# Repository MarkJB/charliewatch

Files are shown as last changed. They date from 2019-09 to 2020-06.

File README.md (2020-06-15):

Charliewatch
---

An "Analog" watch with 72 (60+12) Charlieplexed LEDs. Based on Travis Goodspeed's
GoodWatch21 schematic, using the CC430F5137IRGZR CPU, which doesn't have the LCD
controller of the CC430F6xxx in the GoodWatch.

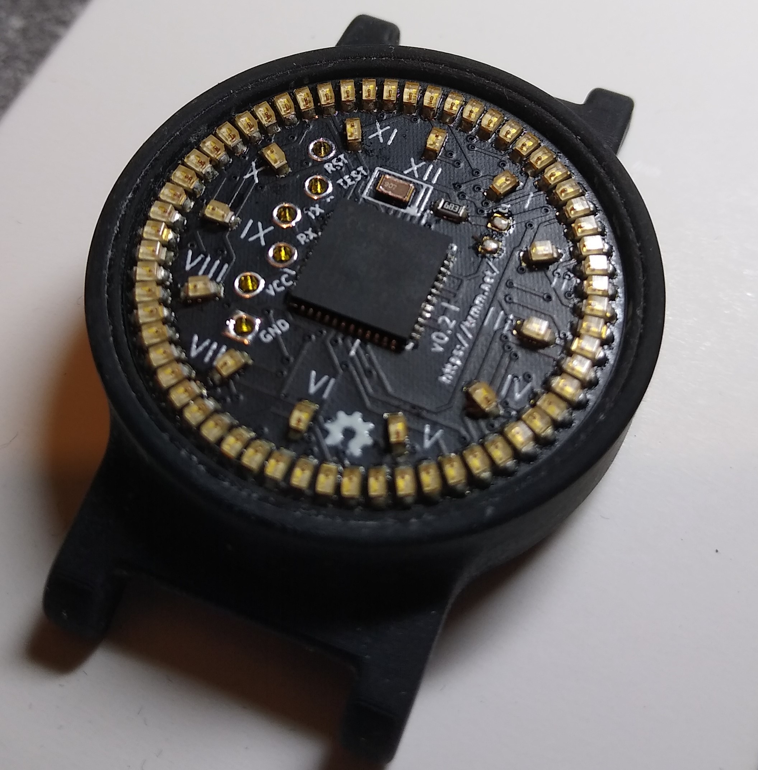
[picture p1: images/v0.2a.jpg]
Modified v0.2 board with Roman Numerals

v0.2 works, although it has no radio parts.  It is exactly 1 square inch
of PCB and should fit in a 38mm or 36mm case.

See it in action: https://www.youtube.com/watch?v=VaebR-6KNXE

[Charliewtch schematic](datasheets/charliewatch.pdf)

Bill Of Materials (BOM)
---
- CC430F5137IRGZR [https://www.mouser.co.uk/ProductDetail/595-CC430F5137IRGZR](https://www.mouser.co.uk/ProductDetail/595-CC430F5137IRGZR)

- 0603 68k Resistor [ERA3AEB683V](https://uk.farnell.com/panasonic/era3aeb683v/res-68k-0-1-0-1w-0603-thin-film/dp/1577630)

- 0603 Red LED [KP-1608EC](https://uk.farnell.com/kingbright/kp-1608ec/led-red-8mcd-625nm-smd/dp/2463988)

- KEYSTONE  3002  Battery Contact, Coin Cell - 20mm, SMD [3002](https://uk.farnell.com/keystone/3002/battery-smd-retainer-20mm/dp/1650693)

- IQD FREQUENCY PRODUCTS  LFXTAL050789  Crystal, 32.768 kHz, SMD, 2mm x 1.2mm, 12.5 pF, 20 ppm, IQXC-25 Series [LFXTAL050789](https://uk.farnell.com/iqd-frequency-products/lfxtal050789/crystal-32-768khz-12-5pf-smd/dp/2449502)

- Push button - Omron [B3U3100P](https://uk.farnell.com/omron/b3u-3000p/tactile-switch-side-actuated-smd/dp/1333655)

Programming
---

Programmed via TI Code Composer Studio using the Programmer/Debugger on the MSP430 FR4133 Launchpad.
http://www.ti.com/tool/MSP-EXP430FR4133

Programming cable
---

From the top of the board: (Wiring from watch to Programmer/Debugger on MSP430 FR4133 Launchpad) 
* TST - SBWTCK
* RST - SBWTDIO
* RX - RXD
* TX - TXD
* VCC - 3V3
* GND - GND

There is also a four-wire setup that might simplify the wiring.
Travis documents it and the power consumption here:
https://github.com/travisgoodspeed/goodwatch/wiki/EnergyTrace

Bricked Launchpad
-----

If you brick your launchpad by running Energia under Linux, it will no
longer program the Charliewatch.  The other weirdness is that `tilib`
can detect the device, but can't write to it unless run as root.

Energy Trace
----
* `libmsp430.so`: https://dlbeer.co.nz/articles/slac460y/index.html
* https://github.com/carrotIndustries/energytrace-util
* Have to update path to `MSP430.h` from the `slac/DLL430_v3/include` directory

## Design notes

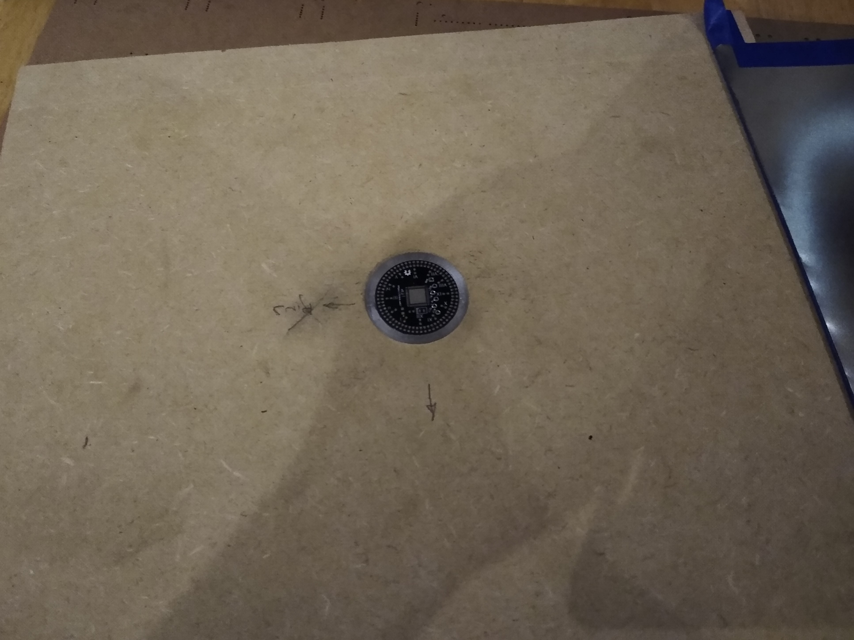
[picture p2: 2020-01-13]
images/pcb_puck3.jpg

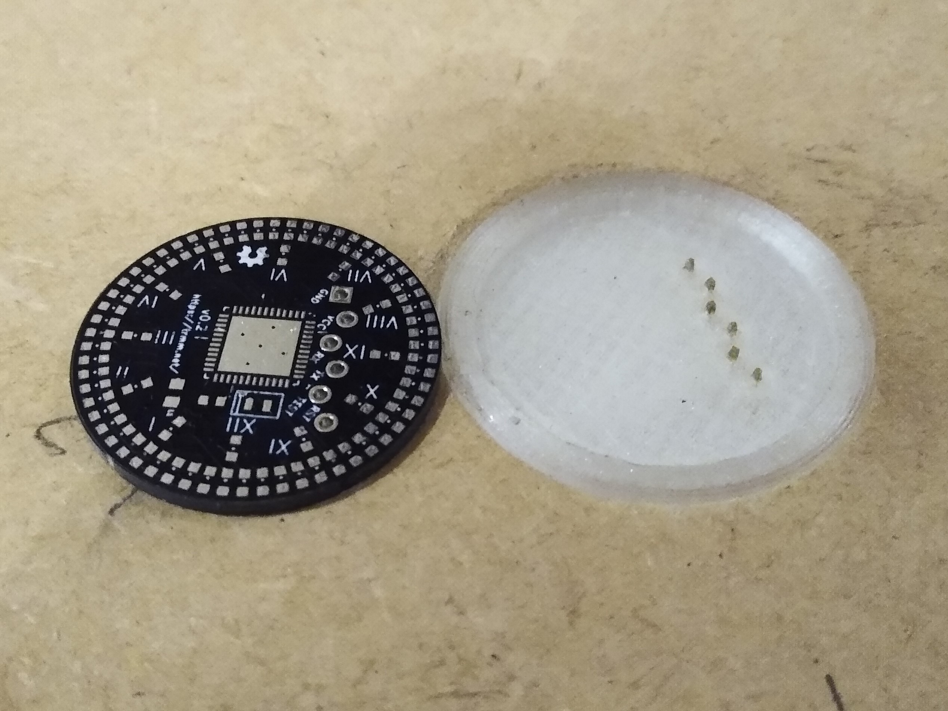
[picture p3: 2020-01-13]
images/pcb_puck2.jpg

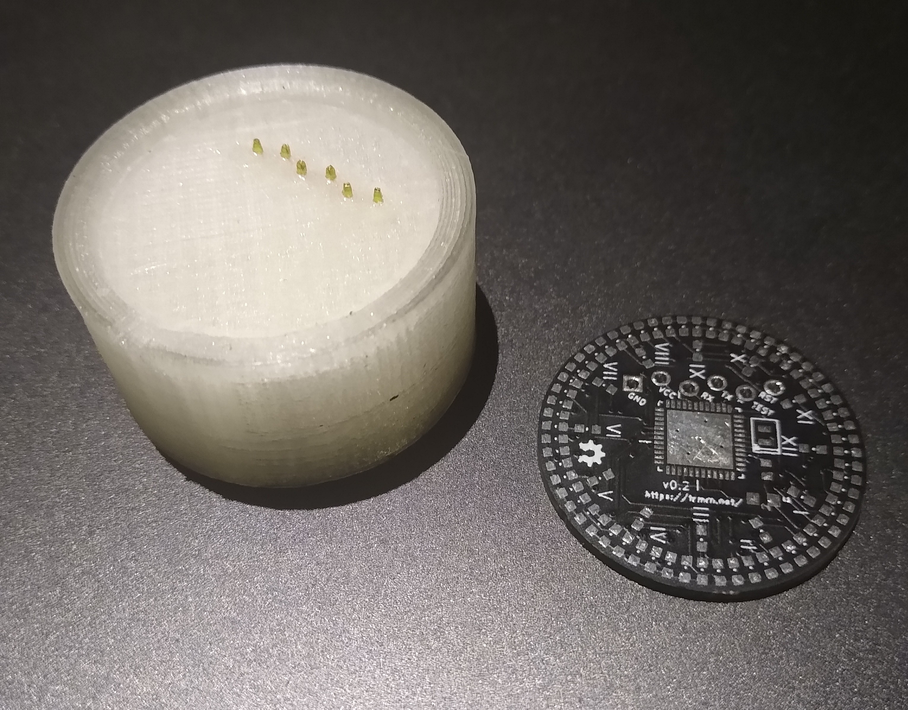
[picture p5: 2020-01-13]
images/pcb_puck1.jpg

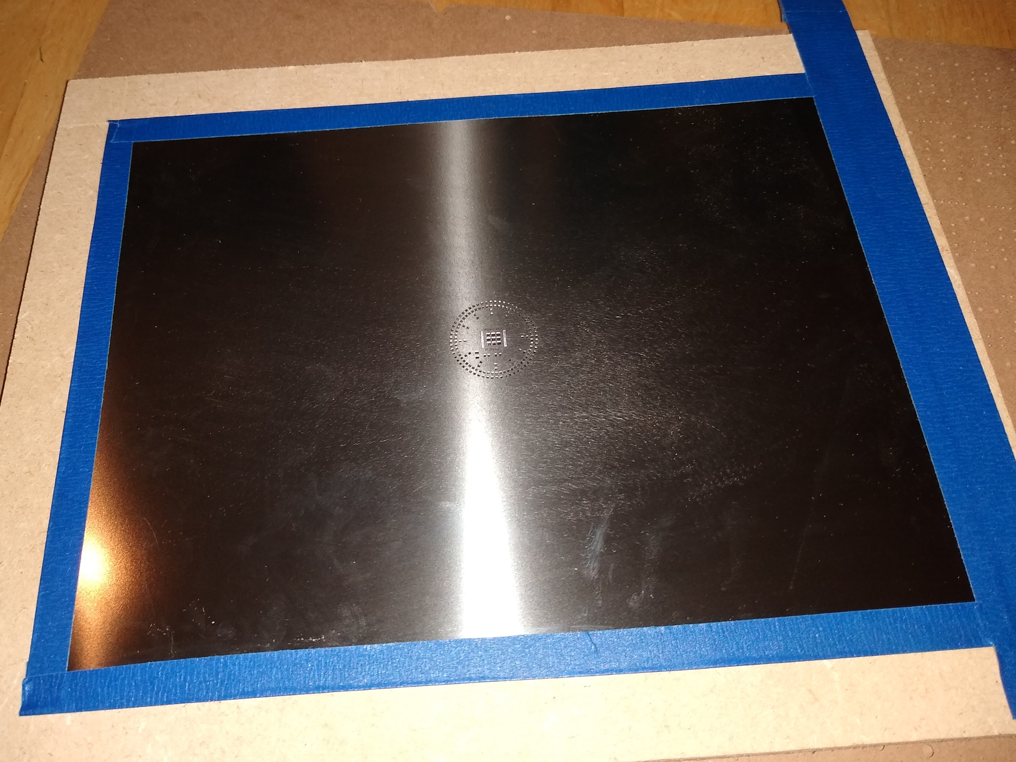
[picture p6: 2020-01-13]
images/pcb_puck4.jpg

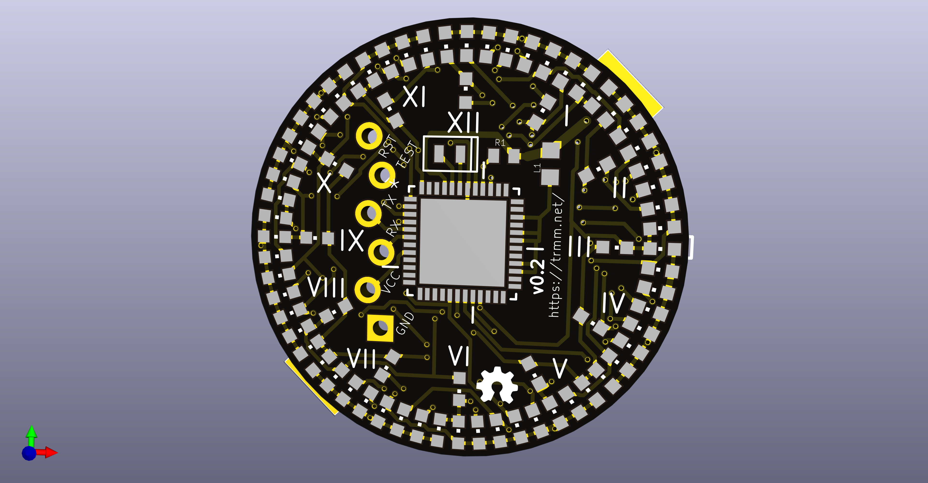
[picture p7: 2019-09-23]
pcb/charliewatch_black_roman_numerals.png

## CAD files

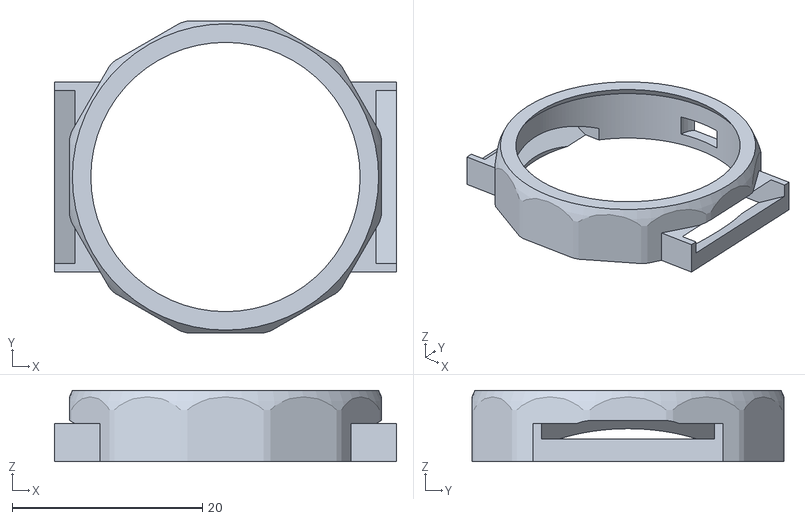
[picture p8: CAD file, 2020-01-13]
case/case.stl
36.0 x 32.8 x 7.50

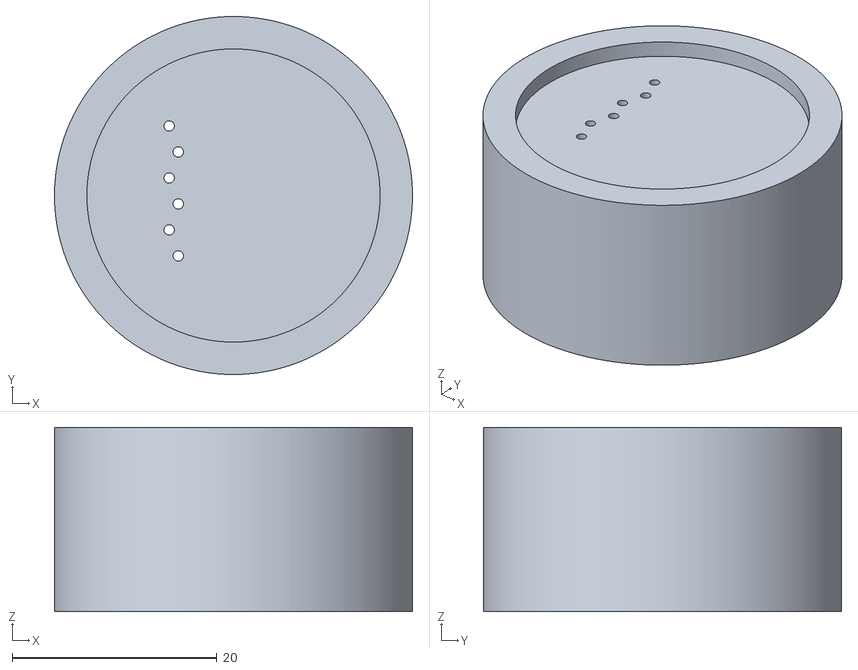
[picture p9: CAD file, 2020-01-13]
pcb/stencil_puck_35mm_drill.stl
35.0 x 35.0 x 18.0

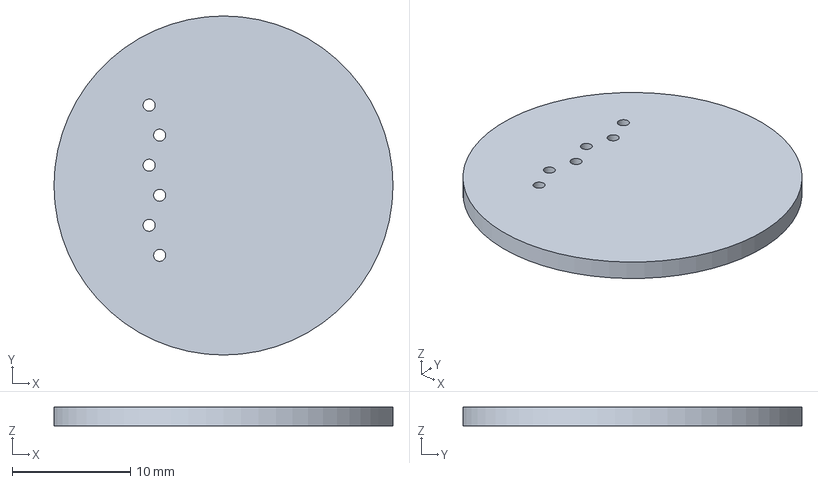
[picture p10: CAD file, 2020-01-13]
pcb/charliewatch-norf-routed.step
28.7 x 28.7 x 1.60 mm

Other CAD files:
case/case.scad
case/case.amf

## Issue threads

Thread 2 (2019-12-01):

No proven BOM

MarkJB, 2019-12-01:
Create a proven BOM (Note: Not yet tested)

Parts used so far:

- CC430F5137IRGZR [https://www.mouser.co.uk/ProductDetail/595-CC430F5137IRGZR](https://www.mouser.co.uk/ProductDetail/595-CC430F5137IRGZR)

- 0603 68k Resistor [ERA3AEB683V](https://uk.farnell.com/panasonic/era3aeb683v/res-68k-0-1-0-1w-0603-thin-film/dp/1577630)

- 0603 Red LED [KP-1608EC](https://uk.farnell.com/kingbright/kp-1608ec/led-red-8mcd-625nm-smd/dp/2463988)

- KEYSTONE  3002  Battery Contact, Coin Cell - 20mm, SMD [3002](https://uk.farnell.com/keystone/3002/battery-smd-retainer-20mm/dp/1650693)

- IQD FREQUENCY PRODUCTS  LFXTAL050789  Crystal, 32.768 kHz, SMD, 2mm x 1.2mm, 12.5 pF, 20 ppm, IQXC-25 Series [LFXTAL050789](https://uk.farnell.com/iqd-frequency-products/lfxtal050789/crystal-32-768khz-12-5pf-smd/dp/2449502)

- Push button - Omron [B3U3100P](https://uk.farnell.com/omron/b3u-3000p/tactile-switch-side-actuated-smd/dp/1333655)

MarkJB, 2020-01-02:
I can confirm that this BOM is correct so far - need to find a suitable button.

MarkJB, 2020-01-08:
Push button is Omron [B3U3100P](https://uk.farnell.com/omron/b3u-3000p/tactile-switch-side-actuated-smd/dp/1333655)

Closed 2020-01-08.

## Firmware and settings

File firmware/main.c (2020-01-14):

/*! \file main.c

  \brief Main module.  This version initializes the hardware and then
   drops to a low power mode, letting the WDT update the LEDs every 16ms

  Schematic and more at https://trmm.net/Charliewatch
*/

#include <msp430.h>
#include <string.h>
#include <stdio.h>
#include <stdlib.h>

#include "rtc.h"
#include "ucs.h"
#include "led.h"
#include "adc.h"
#include "power.h"
#include "button.h"

//! Activates and configures the module, but does not turn on reference.
void ref_init(){
  //Setting the master bit disables legacy mode.
  REFCTL0|=REFMSTR;

  //Wait for register to not be busy before modifying voltage.
  while(REFCTL0 & REFGENBUSY);
  
  //2.5V reference.
  REFCTL0 &= ~BGMODE;
  REFCTL0|=REFVSEL_2;
}


//! Main method.
int main(void)
{
	WDTCTL = WDTPW + WDTHOLD; // Stop WDT

	ref_init();
	//uart_init();

	// drive port J and 1 to ground to avoid CMOS power drain
	PJDIR |=  0xF;
	PJOUT &= ~0xF;
	P1DIR |=  0xF;
	P1OUT &= ~0xF;

	button_init();

	// turn off all the LEDs to reduce power
	led_off();

#if 1
	led_test();
#else
	while(1) {
		led_test();
		delay(1000);
	}
#endif

	rtc_init();
	ucs_init(); // doesn't work if crystal isn't there?

	// Setup and enable WDT 16ms, ACLK, interval timer
	WDTCTL = WDT_ADLY_16;
	SFRIE1 |= WDTIE;

	// go into low power mode
	power_setvcore(0);
	ucs_slow();

	__bis_SR_register(LPM3_bits + GIE);        // Enter LPM3

	// flash the 0 hour so that we know something is wrong
	while(1)
	{
		led_on(60); delay(1);
		led_off(); delay(3);
		led_on(60); delay(1);
		led_off(); delay(6);
	}
}


extern void stopwatch_draw(void);
extern void clockset_draw(void);
extern void animation_draw(void);
extern void lowpwr_draw(void);

static void voltage_draw(void)
{
	unsigned i;
	unsigned raw_volts = adc12_single_conversion(
		REFVSEL_1, ADC12SHT0_10, ADC12INCH_11);


#if 0
	static unsigned bright = 0;
	bright = (bright + 1) % 128;

	for(i = 0 ; i < 12 ; i++)
	{
		if (0 == (raw_volts & (1<<i)))
			continue;
		led_dither(60+i, bright > 64 ? 128 - bright : bright);
	}

	unsigned scaled = raw_volts / 68;
	for(i = 0 ; i < scaled ; i++)
	{
		led_on(i);
	}
#else
	unsigned millivolts = (1250 * (uint32_t) raw_volts) / 1024;
	led_on(60 + (millivolts / 1000));

	unsigned mv = ((millivolts % 1000) * 60) / 1000;
	for(i = 0 ; i < mv ; i++)
	{
		led_on(i);
	}
#endif
		
	led_off();
}

static void (*const modes[])(void) = {
	//voltage_draw,
	animation_draw, //mode 0 display time
	stopwatch_draw, //mode 1 stopwatch
	clockset_draw, //mode 2 (2a) set hours
	clockset_draw, //mode 3 (2b) minutes
	voltage_draw,  //mode 4 hr=3 battery level
	lowpwr_draw,   //mode 5 hr=4 leds off (short press to enable or will timeout)
};

static const unsigned mode_count = sizeof(modes) / sizeof(*modes);
unsigned watch_mode = 0;


//! Watchdog Timer interrupt service routine, calls back to handler functions.
void __attribute__ ((interrupt(WDT_VECTOR)))
watchdog_timer(void)
{
	ucs_fast();

	button_update();

	// long hold advances mode
	if (button_long)
		watch_mode = (watch_mode + 1) % mode_count;

	modes[watch_mode]();

	led_off();
	ucs_slow();
}

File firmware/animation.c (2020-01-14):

/*! \file animation.c

  \brief Drawing functions based on the time.

Animations are drawn:
* When the second hand hits the minute hand
* When the second hand hits the minute hand on a 5 minut emark
* When the second hand hits the hour hand
* When all three hands line up
* At midnight/noon
*/

#include <msp430.h>
#include <string.h>
#include <stdio.h>
#include <stdlib.h>

#include "led.h"
#include "button.h"

extern unsigned watch_mode;

void delay(unsigned len)
{
#if 0
	const uint8_t p2 = P2OUT;
	const uint8_t p3 = P3OUT;

	while(len)
	{
		// toggle the LEDs back on
		P2OUT = p2;
		P3OUT = p3;
		len--;

		// now toggle them off
		P2OUT = 0;
		P3OUT = 0;
	}
#else
	len *= 2;
	while(len)
	{
		asm("");
		len--;
	}
#endif
}


// In normal operation there are four LEDs powered on
// The minute is full bright
// The hour is half bright
// the second is quarter bright
// the previous second fades
uint8_t led_display[] = {};
uint8_t led_bright[] = {};


void led_draw(void)
{
	int i;

	for(i=0 ; i < NUM_DISPLAY ; i++)
	{
		const unsigned led = led_display[i];
		const unsigned bright = led_bright[i];

#if 0
		if (bright > 0)
			led_on(led);

		if (bright > 1)
			delay(bright);
		else
			led_off();
#else
		led_dither(led, bright);
#endif
	}

	led_off();
}


static unsigned animation_counter = 0;
static void (*animation)(unsigned counter) = NULL;

static void sparkle_animation(unsigned count)
{
#if 0
	// should make the sparkles converge inward
	led_on((RTCSEC + rand() % (count/8) - count/16 + 240) % 60);
	led_on((RTCMIN + rand() % (count/8) - count/16 + 240) % 60);
	led_on((RTCHOUR*5 + rand() % (count/8) - count/16 + 240) % 60);
	led_on(rand() % 60);
	led_on(60 + (rand() % 12));
#else
	unsigned i;
	if (count > 72)
		count = 12;
	else
		count /= 8;

	for(i = 0 ; i < count ; i++)
		led_on(rand() % 72);

	// start turning on the hands
	if (count < 20)
	{
		led_on(led_display[0]);
		led_on(led_display[1]);
		led_on(RTCSEC);
	}
#endif
}

// animation 1 for when all the hands align
static void align_animation(unsigned count)
{
	unsigned i;

	if (count > 180)
	{
		// draw out from the minute up to the count
		for(i=0 ; i < 240 - count ; i++)
			led_on((RTCMIN + i + 60) % 60);

		// draw out from the hour hand in reverse
		for(i=0 ; i < (240 - count)/5 ; i ++)
			led_on(60 + (RTCHOUR + i + 12) % 12);
	} else
	if (count > 120)
	{
		// start collapsing back to the minute
		for(i= 0 ; i < count - 120 ; i++)
			led_on((RTCMIN - i + 60) % 60);

		// collapse back to the hour hand
		for(i=0 ; i <= (count - 120)/5 ; i ++)
			led_on(60 + (RTCHOUR - i + 12) % 12);
	} else
	if (count > 60)
	{
		// draw out from the minute up to the count
		for(i=0 ; i < 120 - count ; i++)
			led_on((RTCMIN - i + 60) % 60);

		// draw out from the hour hand in reverse
		for(i=0 ; i <= (120 - count)/5 ; i ++)
			led_on(60 + (RTCHOUR + i + 12) % 12);
	} else {
		// start collapsing back to the minute
		for(i= 0 ; i < count ; i++)
			led_on((RTCMIN + i + 60) % 60);

		// collapse back to the hour hand
		for(i=0 ; i <= count/5 ; i ++)
			led_on(60 + (RTCHOUR - i + 12) % 12);
	}
}

// animation 2 for when all the hands align
static void race_animation(unsigned count)
{
	// second hand races at full speed
	led_display[2] = (RTCMIN + 360 - count) % 60;

	// minute hand at half speed
	led_display[0] = (RTCMIN + 360 - count/2) % 60;

	// hour hand at 1/3 speed
	led_display[1] = (RTCMIN + 360 - count/3) % 60;

	led_draw();
}

// animation for when the hands align at 3 and 9
// rotate start at max speed, rotate stop at half speed,
// makes four revolutions
// count goes from 240 to 0
static void chase_animation(unsigned count)
{
	unsigned i;

	// change the sense of the count
	count = 240 - count;

	if (count < 120)
	{
		// first two laps (0-59), go from slow to fast
		// at the end the entire watch is illuminated
		for(i = count/2 ; i < count ; i++)
			led_on((i + RTCSEC) % 60);
	} else {
		// second two laps, go from fast to slow, undrawing
		// at the end nothing is illuminated
		count -= 120;
		for(i = count ; i < count/2 + 60 ; i++)
			led_on((i + RTCSEC) % 60);
	}

	led_off();
}

// when the second hand lines up with the hour and the minute
// is 180 degrees away
static void opposite_animation(unsigned count)
{
	unsigned i;

	if (count >= 60)
	{
		// grow the bargraph between the two points until they meet
		count = (120 - count) / 2;
		for(i = 0 ; i < count ; i++)
		{
			led_on((RTCSEC + i) % 60);
			led_on((RTCMIN + i) % 60);
		}
	} else
	{
		// retract the bargraph between the two
		count /= 2;
		for(i = 0 ; i <= count ; i++)
		{
			led_on((RTCSEC - i + 60) % 60);
			led_on((RTCMIN - i + 60) % 60);
		}
	}

	// and keep the actual hour on
	led_on(led_display[1]);
}

// rotate all three together
static void triangle_animation(unsigned count)
{
	const unsigned hour = (RTCHOUR % 12) * 5;
	unsigned i;

	if (RTCSEC < RTCMIN)
	{
		// spin all three around twice
		led_on((RTCSEC + 120 - count) % 60);
		led_on((RTCMIN + 120 - count) % 60);
		led_on((hour + 120 - count) % 60);

	} else
	if (count >= 60)
	{
		// grow the bargraph between the three points
		// count goes from 0 - 20
		count = (120 - count) / 3;
		for(i = 0 ; i < count ; i++)
		{
			led_dither((RTCSEC + i) % 60, (20 - count + i)/8);
			led_dither((RTCMIN + i) % 60, (20 - count + i)/8);
			led_dither((hour + i) % 60, (20 - count + i)/8);
		}
	} else
	{
		// retract the bargraph to the three
		// count goes from 20 to 0
		count /= 3;
		for(i = 0 ; i <= count ; i++)
		{
			led_dither((RTCSEC - i + 60) % 60, (count - i)/8);
			led_dither((RTCMIN - i + 60) % 60, (count - i)/8);
			led_dither((hour - i + 60) % 60, (count - i)/8);
		}
	}

	// and keep the actual hour on
	led_on(led_display[1]);
}

static void hour_animation(unsigned count)
{
	// run the hour backwards
	if (3 == (count % 5))
		led_display[1] = 60 + (led_display[1] - 60 - 1 + 12) % 12;

	// and the second hand should match it
	led_display[2] = (led_display[2] + 1) % 60;

	led_draw();
}


static void minute_animation(unsigned count)
{
	// run the minute hand backwards at half speed
	if (0 == (count & 1))
		led_display[0] = (led_display[0] + 60 - 1) % 60;

	// run the second hand forward at full speed
	led_display[2] = (led_display[2] + 1) % 60;

	// if this occured at the start of a new hour,
	// run an hour hand animation, too
	if (RTCMIN == 0 && (count % 5) == 0)
		led_display[1] = 60 + (led_display[1] - 60 - 1 + 12) % 12;

	led_draw();
}

// count will be start at 60
static void new_minute_animation(unsigned count)
{
	// if earlier than 30 minute past the hour,
	//	run the hand forwards to 59
	// otherwise
	//	run the hard backwards to 1
	// reset animation counter when we hit either condition

	if (RTCMIN > 30)
		count = RTCMIN + count - 60;
	else
		count = RTCMIN - count + 60;

	if (count == 0 || count == 59)
		animation_counter = 0;

	led_on(count);
	led_off();

	// ensure that the second hand advances
	led_display[2] = RTCSEC;

	led_draw();
}
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

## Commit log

2019-09-23 Imported PCB to kicad and modified the silkscreen to be Roman Numerals, included zip of gerber files.
    [charliewatch-norf-routed-B.Mask.gbs, charliewatch-norf-routed-B.Paste.gbp, charliewatch-norf-routed-B.SilkS.gbo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]
2020-01-13 add case folder and pcb models
    Added a folder for new case models.
    Moved some images into images folder
    Added step & wrl PCB models for case modelling.
    [case.amf, case.scad, charliewatch-norf-routed.step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]
2020-01-13 Use 'R12' instead of 'R15'
    Used the assembler workaround for RC3 errata as per http://www.ti.com/lit/er/slaz094aa/slaz094aa.pdf.
    This is TIs code but pulled from Travis Goodspeeds 'Goodwatch' repo as the 'R15' version wasn't working for me reliably in CCS and GCC.
    https://github.com/travisgoodspeed/goodwatch/commit/9eab697c9aca721d29e7ae4a1e4f9f9b0aaded59
2020-01-13 Workaround for XT1 stabilization test
    Disable XT1 stabilization test as this stop the watch starting up on the board I built. Seems to run fine without it. Need to determine if this is detremental to normal operation.
2020-01-13 Add case and stencil puck stls
    Add new case stl.
    Add the PCB stencil jig 'puck'. This is a jig with holes for 2.54mm pins that line up with the programming pin holes in the PCB to make lining up with the solder paste screen easier. This is 18mm thi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
    [case.stl, stencil_puck_35mm_drill.stl]
2020-01-14 Add 'leds off' mode
    Added a 'low power' mode where all leds are off until the mode is disabled (short press) and then times out or long press to go back to mode 0 (animation_draw).
    [main.c]
2020-01-14 Auto power off leds on main display
    If enabled time display mode will turn off the leds after 60 seconds. Short press to display time again.
    [animation.c, main.c]
